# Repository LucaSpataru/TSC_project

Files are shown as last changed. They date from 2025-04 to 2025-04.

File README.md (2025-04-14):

# TSC_project
Pentru acest proiect am avut de implementat PCBul unui ebook reader si asamblarea acestuia in carcasa alaturi de o baterie si display.
Primul pas al proiectului a fost creearea schemei electrice ce consta in plasarea si conectarea componentelor.
Componenta principala este microcontrollerul ESP32-C6 care gestioneaza și coordoneaza functionarea celorlalte componente.
# Pini folositi
| Componentă | Pini ESP C6 | Funcție |
|---|---|---|
| SAMACSYS_PARTS_USB4110-GF-AUSB4 | 13 (USB_D-), 14 (USB_D+) | Încărcare baterie via USB |
| QWIIC_RIGHT_ANGLE + BME680 | 19 (SDA), 20 (SCL) | Măsurare temperatură, calitate aer, umiditate (energy mgmt)  |
| 112A-TAAR-R03_ATTEND (SD card port)  | 4 (SS_SD), 6 (SCK), 7 (MOSI), 27 (MISO) | Transfer de date (card SD) |
| FH34SRJ-24S-0.5SH_99_ (Display header)| 7 (MOSI), 6 (SCK), 11 (EPD_CS), 5 (EPD_DC), 21 (EPD_RST), 26 (EPD_BUSY) | Conectare display |
| W25Q512JVEIQ (64MB Flash extern) | 6 (SCK), 7 (MOSI), 27 (MISO), 12 (FLASH_CS) | Stocare de date |
| Butoane (CHANGE, RESET, BOOT) | 23 (IO/CHANGE), 3 (RESET), 15 (IO/BOOT) | Interfață utilizator (comenzi) |
| DS3231SN# (RTC module) | 8 (INT_RTC), 19 (SDA), 20 (SCL), 9 (32KHZ), 16 (RTC_RST) | Ceas în timp real |

De asemenea sunt implementate test paduri, un regulator de tensiune si linii de protectie pentru a putea asigura functionarea corecta a dispozitivului.

Urmatoarul pas a constat in aranjarea componentelor pe placa, decuparea acesteia pentru a se potrivi in carcasa si pentru a nu incurca alte componente precum microcontrollerul si butoanele,
rutarea semnalelor si desenarea planului de masa pe fata si pe spate.
Am intampinat unele probleme precum marimea padurilor pentru componenta MAX17048G+T10 care nu se potriveau cu regulile de rutare, si marimea padurilor bobinei care erau prea mici - am modificat footprintul componentelor.
Am dat approve la 2 erori comune de tip Board Outline Clearance pentru mufa USB4.
Am plasat componentele cat mai eficient, si de asemenea am aranjat ca numele componentelor sa fie vizibile pe silkscreen.

Mai departe am cautat pentru fiecare componenta folosita modele 3D unde am comparat footprinturile pieselor gasite pentru a alege modelul corespunzator.

Ultimul pas a constat in partea 3D unde am plasat placa in carcasa, aici am facut o modificare ce se poate observa in imaginile buttons_mod, deoarece felul in care am pus butoanele se intersectau cu o bucata de plastic
care am micsorat-o. Butoanele ar trebuii sa functioneze fara probleme acum.
Dupa ce m-am asigurat ca mufele sunt aliniate cu componentele ce ies de pe placa, am creeat un model de baterie si unul de display si le-am aranjat si pe acestea in interiorul dispozitivului.

In cele din urma am generat fisierele BOM, PNP si gerbers care se afla in fisierul Manufacturing.
De asemenea am realizat o animatie cu exploded view, dar si un fisier .step cum este specificat in cerinta.
# BOM
| Componentă | Link de cumpărare |
|---|---|
| ADAFRUIT_LEDCHIP-LED0603 | [Mouser](https://ro.mouser.com/ProductDetail/ams-OSRAM/KW-EELP41.RU-S1U1-3K6L-3X4X-5-R18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) |
| SJ | [Mouser](https://ro.mouser.com/ProductDetail/Chip-Quik/WWSWLT.040-200g?qs=i8QVZAFTkqRTFq30mTreAQ%3D%3D) |
| CPH3225A (Supercapacitor)  | [Mouser](https://ro.mouser.com/ProductDetail/Seiko-Semiconductors/CPH3225A?qs=3etwrb1wR%252BhUOph6lAO7eg%3D%3D) |
| DS3231SN# (RTC) | [SnapEDA](https://www.snapeda.com/parts/DS3231SN%23/Analog+Devices/view-part/?ref=eda) |
| ESP32-C6-WROOM-1-N8 | [SnapEDA](https://www.snapeda.com/parts/ESP32-C6-WROOM-1-N8/Espressif+Systems/view-part/?ref=eda) |
| FH34SRJ-24S-0.5SH_99_ | [Mouser](https://www.mouser.co.uk/ProductDetail/Hirose-Connector/FH34SRJ-24S-0.5SH99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) |
| MAX17048G+T10 (Fuel Gauge)| [SnapEDA](https://www.snapeda.com/parts/MAX17048G+T10/Analog+Devices/view-part/?ref=eda) |
| MBR0530 (Schottky Diode)  | [SnapEDA](https://www.snapeda.com/parts/MBR0530/Onsemi/view-part/?ref=eda) |
| PGB1010603MR (TVS Diode)  | [SnapEDA](https://www.snapeda.com/parts/PGB1010603MR/Littelfuse/view-part/?ref=eda) |
| SI1308EDL-T1-GE3 (MOSFET) | [SnapEDA](https://www.snapeda.com/parts/SI1308EDL-T1-GE3/Vishay+Siliconix/view-part/?ref=eda) |
| USBLC6-2SC6Y (ESD Protection)| [SnapEDA](https://www.snapeda.com/parts/USBLC6-2SC6Y/STMicroelectronics/view-part/?ref=eda) |
| W25Q512JVEIQ (Flash Memory)| [SnapEDA](https://www.snapeda.com/parts/W25Q512JVEIQ/Winbond+Electronics/view-part/?ref=eda) |
| XC6220A331MR-G (LDO Regulator)| [Mouser](https://www.mouser.co.uk/ProductDetail/Torex-Semiconductor/XC6220A331MR-G?qs=AsjdqWjXhJ8ZSWznL1J0gg%3D%3D) |
| BD5229G-TR (Voltage Detector)| [Mouser](https://www.mouser.co.uk/ProductDetail/ROHM-Semiconductor/BD5229G-TR?qs=4kLU8WoGk0vvnhrrYwdszw%3D%3D) |
| BME680 (Environmental Sensor)| [Mouser](https://ro.mouser.com/ProductDetail/Bosch-Sensortec/BME680?qs=v271MhAjFHjo0yA%2FC4OnDQ%3D%3D) |
| 112A-TAAR-R03_ATTEND (SD Card Socket)| [DigiKey](https://www.digikey.ro/en/products/detail/attend-technology/112A-TAAR-R03/17633923) |

# Diagrama
OpenBookDiagram

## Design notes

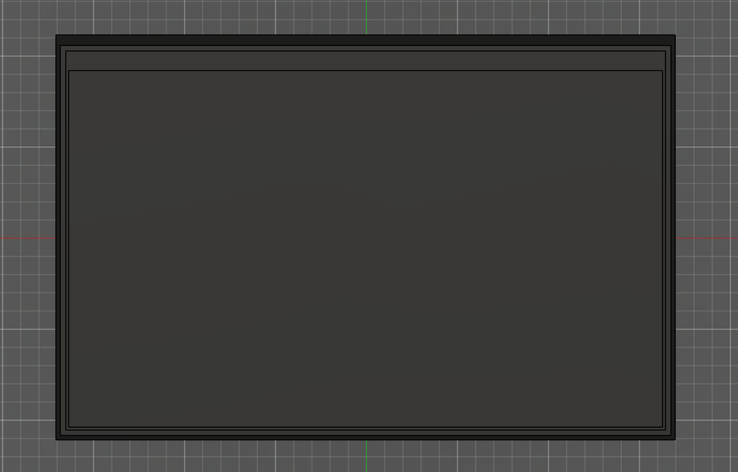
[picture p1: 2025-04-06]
Images/Display_back.png

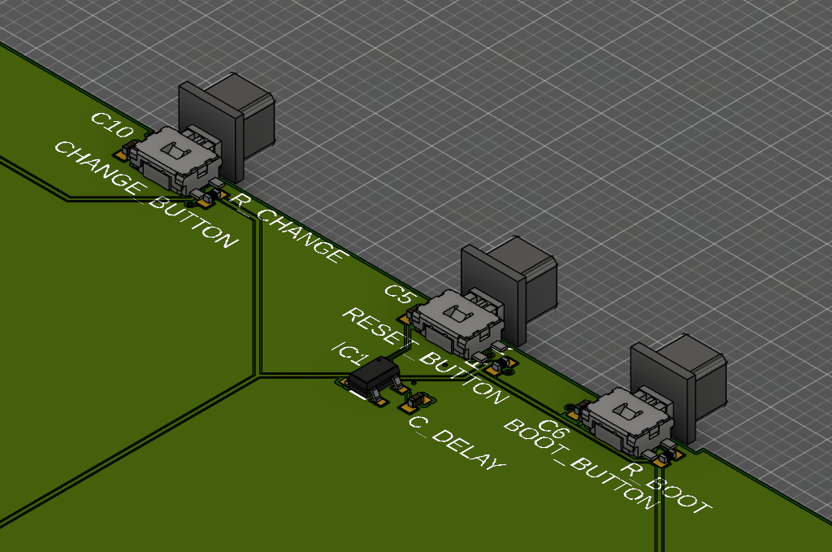
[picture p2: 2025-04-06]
Images/buttons_mod2.png

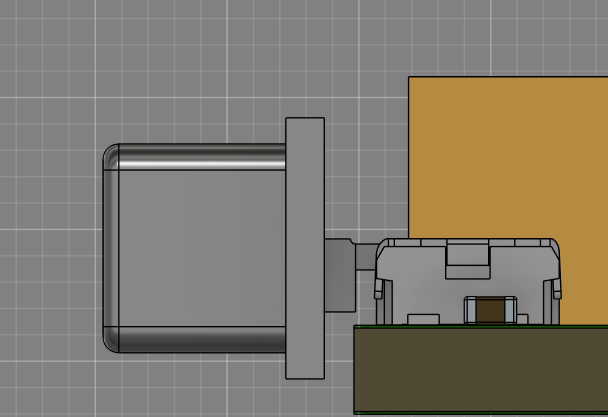
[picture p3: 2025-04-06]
Images/buttons_mod3.png

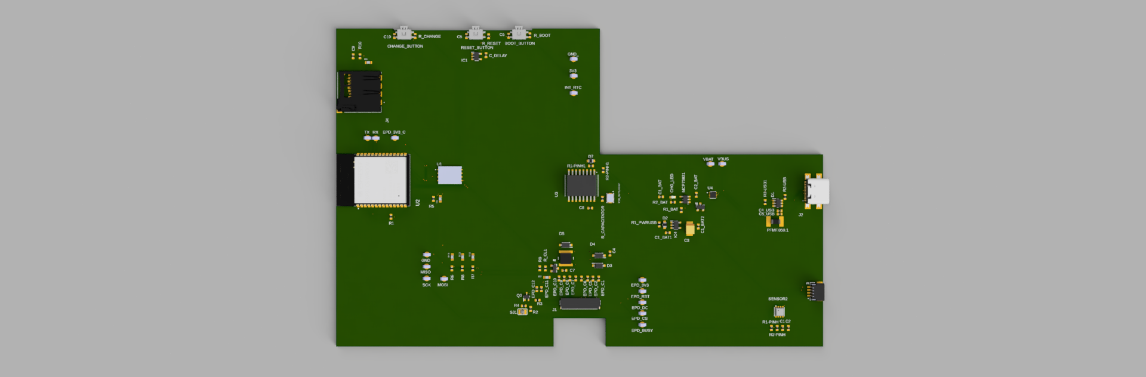
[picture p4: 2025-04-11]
Images/PCB2.png

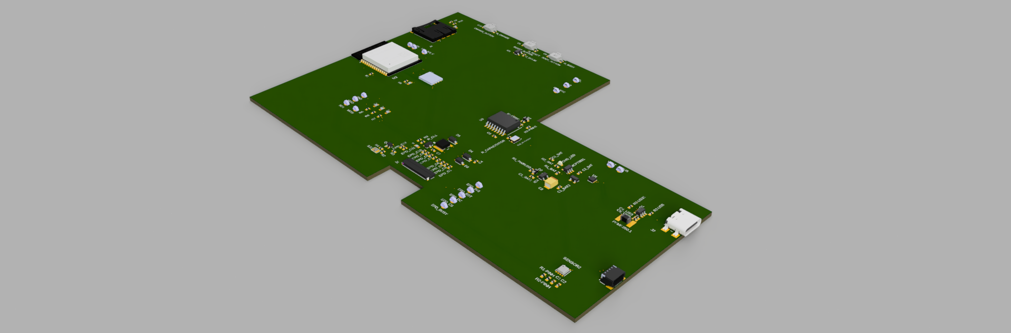
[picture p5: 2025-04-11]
Images/PCB1.png

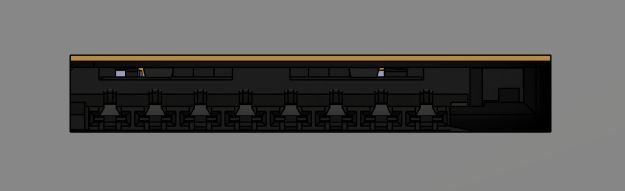
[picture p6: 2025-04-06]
Images/Alignment_2.png

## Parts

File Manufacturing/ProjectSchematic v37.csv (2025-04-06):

Qty | Value | Device | Package | Parts | Description | ARROW_PART_NUMBER | ARROW_PRICE-STOCK | AVAILABILITY | CENTROID_NOT_SPECIFIED | CHECK_PRICES | COPYRIGHT | DATASHEET | DESCRIPTION | DIGIKEY_DESCRIPTION | DIGIKEY_PART_NUMBER | HEIGHT | LEAD_FREE | MANUFACTURER_NAME | MANUFACTURER_PART_NUMBER | MF | MFR_NAME | MOUSER_PART_NUMBER | MOUSER_PRICE-STOCK | MOUSER_TESTING_PART_NUMBER | MOUSER_TESTING_PRICE-STOCK | MP | MPN | PACKAGE | POPULARITY | PREFIX | PRICE | PROD_ID | PURCHASE-URL | ROHS | SNAPEDA_LINK | SPICEMODEL | SPICEPREFIX | TEMPERATURE_RANGE_HIGH | TEMPERATURE_RANGE_LOW | TP_SIGNAL_NAME | VALUE
1 |  | ADAFRUIT_LEDCHIP-LED0603 | ADAFRUIT_CHIP-LED0603 | CHG_LED | LED
1 |  | SJ | SJ | SJ1 | SMD solder JUMPER |  |  |  |  |  |  |  |  |  |  |  |  |  |  |  |  |  |  |  |  |  |  |  | 3
1 | 0.1uF/50V | ESP32_WROVER_EAGLE-LTSPICE_CC0402 | ESP32_WROVER_EAGLE-LTSPICE_C0402 | EPD_C5 | CAPACITOR, European symbol |  |  |  |  |  |  |  |  |  |  |  |  |  |  |  |  |  |  |  |  |  |  |  |  |  |  |  |  |  |  | NONE | C
1 | 0.47 | ESP32_WROVER_EAGLE-LTSPICE_RR0402 | ESP32_WROVER_EAGLE-LTSPICE_R0402 | R3 | RESISTOR, European symbol |  |  |  |  |  |  |  |  |  |  |  |  |  |  |  |  |  |  |  |  |  |  |  |  |  |  |  |  |  |  | NONE | R
1 | 100k | ESP32_WROVER_EAGLE-LTSPICE_RR0402 | ESP32_WROVER_EAGLE-LTSPICE_R0402 | R1_PWRUSB | RESISTOR, European symbol |  |  |  |  |  |  |  |  |  |  |  |  |  |  |  |  |  |  |  |  |  |  |  |  |  |  |  |  |  |  | NONE | R
8 | 100nF | ESP32_WROVER_EAGLE-LTSPICE_CC0402 | ESP32_WROVER_EAGLE-LTSPICE_C0402 | C1, C2, C4_USB, C6, C8, C9, C10, C_DELAY | CAPACITOR, European symbol |  |  |  |  |  |  |  |  |  |  |  |  |  |  |  |  |  |  |  |  |  |  |  |  |  |  |  |  |  |  | NONE | C
1 | 100uF TANT | RCL_CPOL-EUCT3528 | RCL_CT3528 | C3 | POLARIZED CAPACITOR, European symbol |  |  |  |  |  |  |  |  |  |  |  |  |  |  |  |  |  |  |  |  |  |  |  | 0 |  |  |  |  |  |  |  | C
16 | 10k | ESP32_WROVER_EAGLE-LTSPICE_RR0402 | ESP32_WROVER_EAGLE-LTSPICE_R0402 | R1, R1-PINH, R1-PINH1, R2-PINH, R2-PINH1, R4, R5, R6, R7, R8, R9, R10, R_BOOT, R_CHANGE, R_CL1, R_RESET | RESISTOR, European symbol |  |  |  |  |  |  |  |  |  |  |  |  |  |  |  |  |  |  |  |  |  |  |  |  |  |  |  |  |  |  | NONE | R
1 | 10uF | ESP32_WROVER_EAGLE-LTSPICE_CC0402 | ESP32_WROVER_EAGLE-LTSPICE_C0402 | C7 | CAPACITOR, European symbol |  |  |  |  |  |  |  |  |  |  |  |  |  |  |  |  |  |  |  |  |  |  |  |  |  |  |  |  |  |  | NONE | C
1 | 112A-TAAR-R03_ATTEND | 112A-TAAR-R03_ATTEND | 112ATAARR03ATTEND | J4 | Micro SD Card Socket, Push-Push Type, Top Mount, SMT, H=1.83mm, 10u |  |  |  |  |  |  |  | Micro SD Card Socket | Push-Push Type | Top Mount | SMT | H=1.83mm | 10u |  |  | 1.9mm |  | ATTEND | 112A-TAAR-R03 ATTEND
1 | 15 | ESP32_WROVER_EAGLE-LTSPICE_RR0402 | ESP32_WROVER_EAGLE-LTSPICE_R0402 | R_CAPACITATOR | RESISTOR, European symbol |  |  |  |  |  |  |  |  |  |  |  |  |  |  |  |  |  |  |  |  |  |  |  |  |  |  |  |  |  |  | NONE | R
1 | 1uF | ESP32_WROVER_EAGLE-LTSPICE_CC0402 | ESP32_WROVER_EAGLE-LTSPICE_C0402 | C5 | CAPACITOR, European symbol |  |  |  |  |  |  |  |  |  |  |  |  |  |  |  |  |  |  |  |  |  |  |  |  |  |  |  |  |  |  | NONE | C
9 | 1uF/50V | ESP32_WROVER_EAGLE-LTSPICE_CC0402 | ESP32_WROVER_EAGLE-LTSPICE_C0402 | EPD_C1, EPD_C2, EPD_C6, EPD_C7, EPD_C8, EPD_C9, EPD_C10, EPD_C11, EPD_C12 | CAPACITOR, European symbol |  |  |  |  |  |  |  |  |  |  |  |  |  |  |  |  |  |  |  |  |  |  |  |  |  |  |  |  |  |  | NONE | C
1 | 2.2 | ESP32_WROVER_EAGLE-LTSPICE_RR0402 | ESP32_WROVER_EAGLE-LTSPICE_R0402 | R2 | RESISTOR, European symbol |  |  |  |  |  |  |  |  |  |  |  |  |  |  |  |  |  |  |  |  |  |  |  |  |  |  |  |  |  |  | NONE | R
1 | 200 | ESP32_WROVER_EAGLE-LTSPICE_RR0402 | ESP32_WROVER_EAGLE-LTSPICE_R0402 | R1_BAT | RESISTOR, European symbol |  |  |  |  |  |  |  |  |  |  |  |  |  |  |  |  |  |  |  |  |  |  |  |  |  |  |  |  |  |  | NONE | R
2 | 20V/4.2A/52mO/1.4W | ESP32_WROVER_SPARKFUN-DISCRETESEMI_MOSFET_PCH-DMG2305UX-7 | ESP32_WROVER_SPARKFUN-DISCRETESEMI_SOT23-3 | Q1, Q2 | P-channel MOSFETs |  |  |  |  |  |  |  |  |  |  |  |  |  |  |  |  |  |  |  |  |  |  |  |  |  |  | TRAN-14388 |  |  |  |  |  |  |  |  | 20V/4.2A/52mO/1.4W
1 | 2k | ESP32_WROVER_EAGLE-LTSPICE_RR0402 | ESP32_WROVER_EAGLE-LTSPICE_R0402 | R2_BAT | RESISTOR, European symbol |  |  |  |  |  |  |  |  |  |  |  |  |  |  |  |  |  |  |  |  |  |  |  |  |  |  |  |  |  |  | NONE | R
4 | 4.7uF | ESP32_WROVER_EAGLE-LTSPICE_CC0402 | ESP32_WROVER_EAGLE-LTSPICE_C0402 | C1_BAT, C1_BAT1, C2_BAT, C5_USB | CAPACITOR, European symbol |  |  |  |  |  |  |  |  |  |  |  |  |  |  |  |  |  |  |  |  |  |  |  |  |  |  |  |  |  |  | NONE | C
1 | 4.7uF/25V | ESP32_WROVER_EAGLE-LTSPICE_CC0402 | ESP32_WROVER_EAGLE-LTSPICE_C0402 | C4 | CAPACITOR, European symbol |  |  |  |  |  |  |  |  |  |  |  |  |  |  |  |  |  |  |  |  |  |  |  |  |  |  |  |  |  |  | NONE | C
1 | 4.7uF\ | ESP32_WROVER_EAGLE-LTSPICE_CC0402 | ESP32_WROVER_EAGLE-LTSPICE_C0402 | C1_BAT2 | CAPACITOR, European symbol |  |  |  |  |  |  |  |  |  |  |  |  |  |  |  |  |  |  |  |  |  |  |  |  |  |  |  |  |  |  | NONE | C
2 | 5k1 | ESP32_WROVER_EAGLE-LTSPICE_RR0402 | ESP32_WROVER_EAGLE-LTSPICE_R0402 | R2-USB, R2-USB1 | RESISTOR, European symbol |  |  |  |  |  |  |  |  |  |  |  |  |  |  |  |  |  |  |  |  |  |  |  |  |  |  |  |  |  |  | NONE | R
1 | 68uH | 744043680IND_4828-WE-TPC_WRE | IND_4828-WE-TPC_WRE | L1 |  |  |  |  |  |  | Copyright (C) 2024 Ultra Librarian. All rights reserved. |  |  |  |  |  |  |  | 744043680 |  | Wurth Electronics
1 | BD5229G-TR | BD5229G-TR | SOT95P280X125-5N | IC1 | Voltage Detector with Adjustable Delay Time: CMOS processes are utilized to develop high precision, low current consumption CMOS reset ICs that allow arbitrary setting of the delay time. The extensive lineup includes both Nch Open Drain and CMOS output types in a wide range of detection voltages (from 2.3V to 6.0V, in 0.1V steps), enabling selection of the ideal solution based on customer requirements. In addition, the entire series is of course both lead-free and RoHS-compliant. |  |  |  |  |  |  |  | Voltage Detector with Adjustable Delay Time: CMOS processes are utilized to develop high precision | low current consumption CMOS reset ICs that allow arbitrary setting of the delay time. The extensive lineup includes both Nch Open Drain and CMOS output types in a wide range of detection voltages (from 2.3V to 6.0V | in 0.1V steps) | enabling selection of the ideal solution based on customer requirements. In addition | the entire series is of course both lead-free and RoHS-compliant. |  |  | 1.25mm |  | ROHM Semiconductor | BD5229G-TR |  |  | 755-BD5229G-TR | https://www.mouser.co.uk/ProductDetail/ROHM-Semiconductor/BD5229G-TR?qs=4kLU8WoGk0vvnhrrYwdszw%3D%3D
1 | BME680 | ESP32_WROVER_BME680_BME680 | ESP32_WROVER_BME680_PSON80P300X300X100-8N | SENSOR2 | Integrated Environmental Unit |  |  | Unavailable |  |  |  |  | Integrated Environmental Unit |  |  |  |  |  |  | Bosch Sensortec |  |  |  |  |  | BME680 |  | LGA-8 Bosch Tools |  |  | None
3 | BUTTON_CUSYOMV1 | BUTTON_CUSYOMV1 | MYBUTTON | BOOT_BUTTON, CHANGE_BUTTON, RESET_BUTTON
1 | CPH3225A | CPH3225A | CAPCP3225X100N | C10_SUPERCAP | Cap 0.011F 3.3V 1210 Flat Check availability |  |  | Not in stock |  | https://www.snapeda.com/parts/CPH3225A/Seiko+Instruments/view-part/?ref=eda |  |  | 11 mF (EDLC) Supercapacitor 3.3 V 1210 (3225 Metric) - - |  |  |  |  |  |  | Seiko Instruments |  |  |  |  |  | CPH3225A |  | 1210 Seiko |  |  | None |  | https://www.snapeda.com/api/url_track_click_mouser/?unipart_id=562593&manufacturer=Seiko Instruments&part_name=CPH3225A&search_term=None |  | https://www.snapeda.com/parts/CPH3225A/Seiko+Instruments/view-part/?ref=snap
1 | DS3231SN# | DS3231SN# | SOIC127P1032X265-16N | U3 | Real Time Clock Serial 16-Pin SOIC W T/R Check availability |  |  | In Stock |  | https://www.snapeda.com/parts/DS3231SN%23/Analog+Devices/view-part/?ref=eda |  |  | Extremely Accurate I²C-Integrated RTC/TCXO/Crystal |  |  |  |  |  |  | Analog Devices |  |  |  |  |  | DS3231SN# |  | SOIC-16 Maxim |  |  | None |  | https://www.snapeda.com/api/url_track_click_mouser/?unipart_id=99048&manufacturer=Analog Devices&part_name=DS3231SN#&search_term=None |  | https://www.snapeda.com/parts/DS3231SN%23/Analog+Devices/view-part/?ref=snap
1 | ESP32-C6-WROOM-1-N8 | ESP32-C6-WROOM-1-N8 | XCVR_ESP32-C6-WROOM-1-N8 | U2 | Check availability |  |  | In Stock |  | https://www.snapeda.com/parts/ESP32-C6-WROOM-1-N8/Espressif+Systems/view-part/?ref=eda |  |  | Multiprotocol Modules ESP32-C6 module | Wi-Fi 6 in 2.4 GHz band | Bluetooth 5 | Zigbee 3.0 and Thread. ESP34-WROOM Compatible - ENGINEERING SAMPLE |  |  |  |  |  |  | Espressif Systems |  |  |  |  |  | ESP32-C6-WROOM-1-N8 |  | None |  |  | None |  |  |  | https://www.snapeda.com/parts/ESP32-C6-WROOM-1-N8/Espressif+Systems/view-part/?ref=snap
1 | ESP32C6_VARISTORCN1812 | ESP32C6_VARISTORCN1812 | ESP32C6_VARISTOR_CT/CN1812 | PFMF.050.1 | VARISTOR |  |  |  |  |  |  |  |  |  |  |  |  |  |  |  |  |  |  |  |  |  |  |  | 0
2 | ESP32_WROVER_AVX---SD0805S020S1R0_AVX_SD0805S020S1R0_0_0AVX_SD0805S020S1R0_0_0 | ESP32_WROVER_AVX---SD0805S020S1R0_AVX_SD0805S020S1R0_0_0AVX_SD0805S020S1R0_0_0 | ESP32_WROVER_AVX---SD0805S020S1R0_AVX_SD0805S020S1R0_0 | D2, D7 | Schottky Barrier Rectifier Diode |  |  |  | No |  |  | http://datasheets.avx.com/schottky.pdf |  | DIODE SCHOTTKY 20V 1A 0805 | 478-7800-1-ND |  | yes |  |  | AVX |  | 581-SD0805S020S1R0 |  |  |  |  |  | 0805 (2012 metric) |  | D |  |  |  | yes |  |  |  | +125°C | -55°C
1 | ESP32_WROVER_SPARKFUN-IC-POWER_MCP73831 | ESP32_WROVER_SPARKFUN-IC-POWER_MCP73831 | ESP32_WROVER_SPARKFUN-IC-POWER_SOT23-5 | MCP73831 | MCP73831T Li-Ion, Li-Pol Controller |  |  |  |  |  |  |  |  |  |  |  |  |  |  |  |  |  |  |  |  |  |  |  |  |  |  | IC-09995
1 | FH34SRJ-24S-0.5SH_99_ | FH34SRJ-24S-0.5SH_99_ | FH34SRJ24S05SH99 | J1 | (0.50mm) Surface Mount, Right Angle |  |  |  |  |  |  |  | 24 Position FFC | FPC Connector Contacts | (0.50mm) Surface Mount | Right Angle |  |  | 1.1mm |  | Hirose | FH34SRJ-24S-0.5SH(99) |  |  | 798-FH34SRJ24S05SH99 | https://www.mouser.co.uk/ProductDetail/Hirose-Connector/FH34SRJ-24S-0.5SH99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
1 | MAX17048G+T10 | MAX17048G+T10 | SON50P200X200X80-9N | U4 | Check availability |  |  | In Stock |  | https://www.snapeda.com/parts/MAX17048G+T10/Analog+Devices/view-part/?ref=eda |  |  | 3µA 1-Cell/2-Cell Fuel Gauge with ModelGauge |  |  |  |  |  |  | Analog Devices |  |  |  |  |  | MAX17048G+T10 |  | TDFN-8 Maxim |  |  | None |  | https://www.snapeda.com/api/url_track_click_mouser/?unipart_id=329239&manufacturer=Analog Devices&part_name=MAX17048G+T10&search_term=None |  | https://www.snapeda.com/parts/MAX17048G+T10/Analog+Devices/view-part/?ref=snap
3 | MBR0530 | MBR0530 | SOD3716X135N | D3, D4, D5 | ON SEMICONDUCTOR - MBR0530 - DIODE, SCHOTTKY, 0.5A, 30V, SOD-123 |  |  | In Stock |  | https://www.snapeda.com/parts/MBR0530/Onsemi/view-part/?ref=eda |  |  | Diode Schottky 30 V 500mA Surface Mount SOD-123 |  |  |  |  |  |  | ON Semiconductor |  |  |  |  |  | MBR0530 |  | SOD-123-2 ON Semiconductor |  |  | None |  | https://www.snapeda.com/api/url_track_click_mouser/?unipart_id=179458&manufacturer=ON Semiconductor&part_name=MBR0530&search_term=None |  | https://www.snapeda.com/parts/MBR0530/Onsemi/view-part/?ref=snap
6 | PGB1010603MR | PGB1010603MR | DIOC1608X36N | D6, D8, D9, D10, D11, D12 | Check availability |  |  | In Stock |  | https://www.snapeda.com/parts/PGB1010603MR/Littelfuse/view-part/?ref=eda |  |  | 150V (Typ) Clamp - Ipp Tvs Diode Surface Mount 0603 (1608 Metric) |  |  |  |  |  |  | Littelfuse Inc. |  |  |  |  |  | PGB1010603MR |  | 0603 Littelfuse Inc. |  |  | None |  | https://www.snapeda.com/api/url_track_click_mouser/?unipart_id=5659453&manufacturer=Littelfuse Inc.&part_name=PGB1010603MR&search_term=None |  | https://www.snapeda.com/parts/PGB1010603MR/Littelfuse/view-part/?ref=snap
1 | QWIIC_RIGHT_ANGLE | QWIIC_CONNECTORJS-1MM | JST04_1MM_RA | J3 | SparkFun I2C Standard Qwiic Connector |  |  |  |  |  |  |  |  |  |  |  |  |  |  |  |  |  |  |  |  |  |  |  |  |  |  | CONN-13694 |  |  |  |  |  |  |  |  | QWIIC_RIGHT_ANGLE
1 | SAMACSYS_PARTS_USB4110-GF-AUSB4 | SAMACSYS_PARTS_USB4110-GF-AUSB4 | SAMACSYS_PARTS_USB4110GFA | J2 | CONN USB 2.0 TYPE-C R/A SMT
1 | SI1308EDL-T1-GE3 | SI1308EDL-T1-GE3 | SOT65P210X110-3N | Q3 | MOSFET N-Ch 30V 1.5A TrenchFET SC70 Vishay Si1308EDL-T1-GE3 N-channel MOSFET Transistor, 1.5 A, 30 V, 3-Pin SC-70 |  |  | In Stock |  | https://www.snapeda.com/parts/SI1308EDL-T1-GE3/Vishay+Siliconix/view-part/?ref=eda |  |  | Si1308EDL-T1-GE3 N-channel MOSFET Transistor | 1.5 A | 30 V | 3-Pin SC-70 | Siliconix / Vishay SI1308EDL-T1-GE3 |  |  |  |  |  |  | Vishay Siliconix |  |  |  |  |  | SI1308EDL-T1-GE3 |  | SOT-323 Vishay Semiconductor |  |  | None |  | https://www.snapeda.com/api/url_track_click_mouser/?unipart_id=274603&manufacturer=Vishay Siliconix&part_name=SI1308EDL-T1-GE3&search_term=None |  | https://www.snapeda.com/parts/SI1308EDL-T1-GE3/Vishay+Siliconix/view-part/?ref=snap
17 | TPTP20R | TPTP20R | TP20R | 3V3, EPD_3V3, EPD_3V3_C, EPD_BUSY, EPD_CS, EPD_DC, EPD_RST, GND, GND_, INT_RTC, MISO, MOSI, RX, SCK, TX, VBAT, VBUS | Test pad |  |  |  |  |  |  |  |  |  |  |  |  |  |  |  |  |  |  |  |  |  |  |  | 2
1 | USBLC6-2SC6Y | USBLC6-2SC6Y | SOT95P280X145-6N | D1 | Low Cap. ESD Protection Auto SOT-23-6 STMicroelectronics USBLC6-2SC6Y, Dual Uni-Directional TVS Diode Array, 6-Pin SOT-23 |  |  | In Stock |  | https://www.snapeda.com/parts/USBLC6-2SC6Y/STMicroelectronics/view-part/?ref=eda |  |  | 17V Clamp 5A (8/20µs) Ipp Tvs Diode Surface Mount SOT-23-6 |  |  |  |  |  |  | STMicroelectronics |  |  |  |  |  | USBLC6-2SC6Y |  | SOT-23-6 STMicroelectronics |  |  | None |  |  |  | https://www.snapeda.com/parts/USBLC6-2SC6Y/STMicroelectronics/view-part/?ref=snap
1 | W25Q512JVEIQ | W25Q512JVEIQ | SON127P600X800X80-9N | U1 | Check availability |  |  | In Stock |  | https://www.snapeda.com/parts/W25Q512JVEIQ/Winbond+Electronics/view-part/?ref=eda |  |  | FLASH - NOR Memory IC 512Mb (64M x 8) SPI - Quad I/O 133 MHz 8-WSON (8x6) |  |  |  |  |  |  | Winbond Electronics |  |  |  |  |  | W25Q512JVEIQ |  | Package |  |  | None |  |  |  | https://www.snapeda.com/parts/W25Q512JVEIQ/Winbond+Electronics/view-part/?ref=snap
1 | XC6220A331MR-G | XC6220A331MR-G | SOT95P280X120-5N | IC4 | LDO Voltage Regulators |  |  |  |  |  |  |  | LDO Voltage Regulators |  |  | 1.2mm |  | Torex | XC6220A331MR-G |  |  | 865-XC6220A331MR-G | https://www.mouser.co.uk/ProductDetail/Torex-Semiconductor/XC6220A331MR-G?qs=AsjdqWjXhJ8ZSWznL1J0gg%3D%3D

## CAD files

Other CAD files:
Mechanical/ProjectDesign.f3z

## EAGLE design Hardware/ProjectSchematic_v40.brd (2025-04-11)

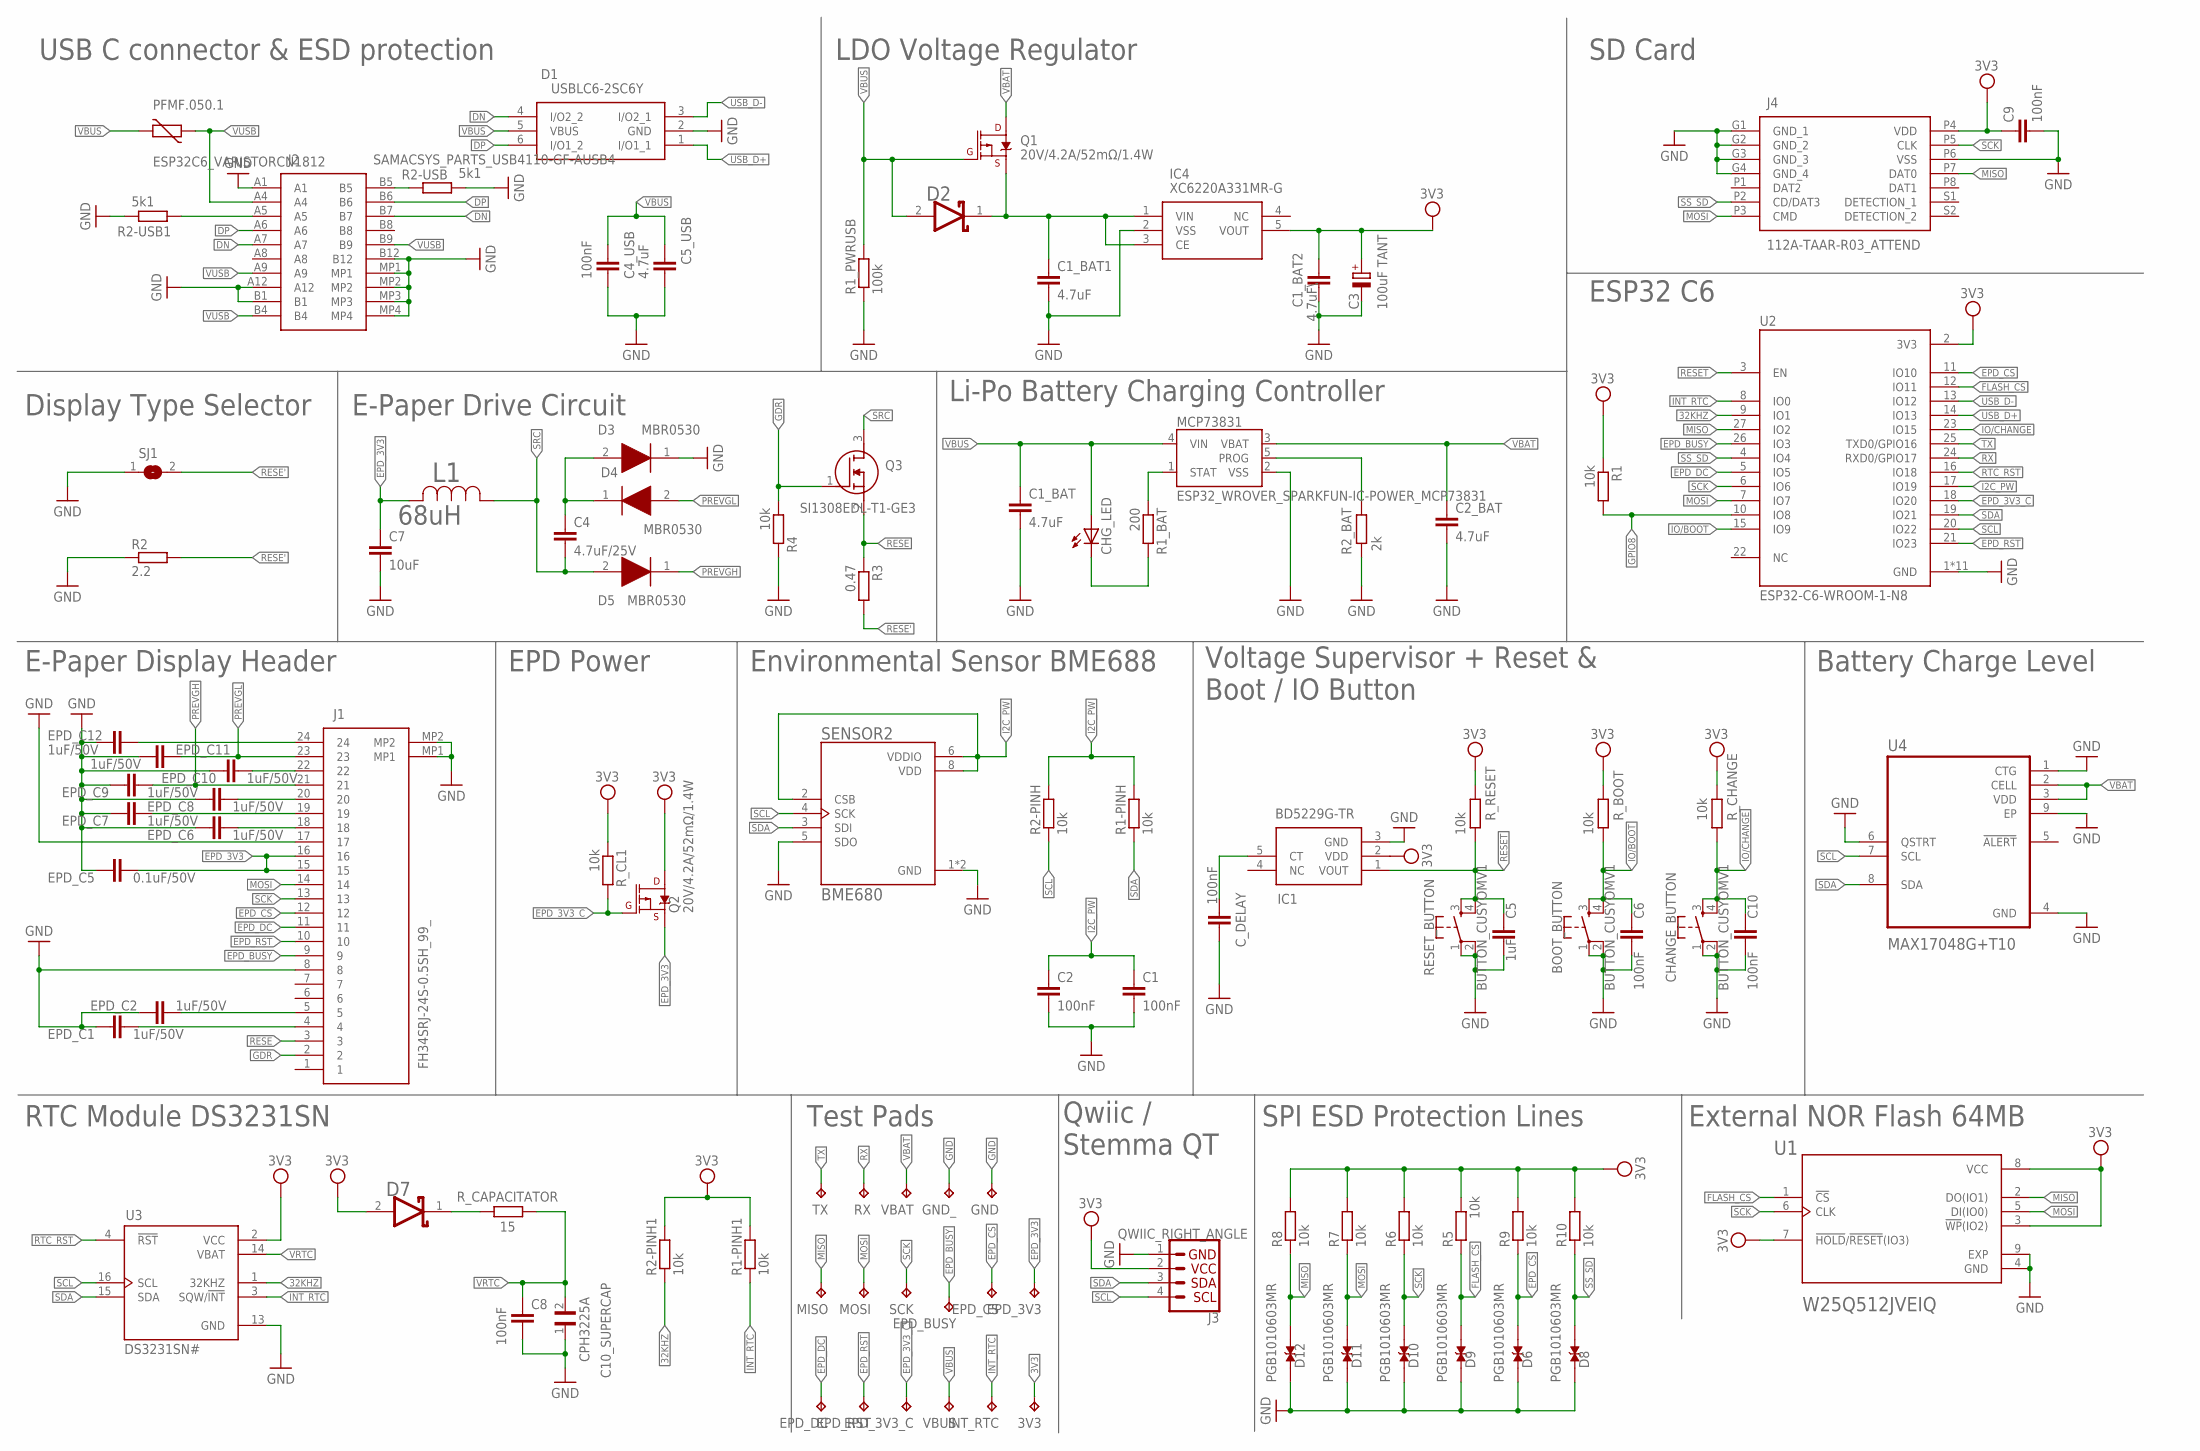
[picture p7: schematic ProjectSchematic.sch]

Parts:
3V3: TPTP20R; TP20R
BOOT_BUTTON: BUTTON_CUSYOMV1; MYBUTTON
C1, C2, C4_USB, C6, C8, C9, C10: 100nF; ESP32_WROVER_EAGLE-LTSPICE_C0402
C1_BAT, C1_BAT1, C2_BAT, C5_USB: 4.7uF; ESP32_WROVER_EAGLE-LTSPICE_C0402
C1_BAT2: 4.7uF\; ESP32_WROVER_EAGLE-LTSPICE_C0402
C3: 100uF TANT; RCL_CT3528
C4: 4.7uF/25V; ESP32_WROVER_EAGLE-LTSPICE_C0402
C5: 1uF; ESP32_WROVER_EAGLE-LTSPICE_C0402
C7: 10uF; ESP32_WROVER_EAGLE-LTSPICE_C0402
C10_SUPERCAP: CPH3225A; CAPCP3225X100N
CHANGE_BUTTON: BUTTON_CUSYOMV1; MYBUTTON
CHG_LED: ADAFRUIT_LEDCHIP-LED0603; ADAFRUIT_CHIP-LED0603
C_DELAY: 100nF; ESP32_WROVER_EAGLE-LTSPICE_C0402
D1: USBLC6-2SC6Y; SOT95P280X145-6N
D2, D7: ESP32_WROVER_AVX---SD0805S020S1R0_AVX_SD0805S020S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; ESP32_WROVER_AVX---SD0805S020S1R0_AVX_SD0805S020S1R0_0
D3, D4, D5: MBR0530; SOD3716X135N
D6, D8, D9, D10, D11, D12: PGB1010603MR; DIOC1608X36N
EPD_3V3, EPD_3V3_C: TPTP20R; TP20R
EPD_BUSY: TPTP20R; TP20R
EPD_C1, EPD_C2, EPD_C6, EPD_C7, EPD_C8, EPD_C9, EPD_C10, EPD_C11, EPD_C12: 1uF/50V; ESP32_WROVER_EAGLE-LTSPICE_C0402
EPD_C5: 0.1uF/50V; ESP32_WROVER_EAGLE-LTSPICE_C0402
EPD_CS: TPTP20R; TP20R
EPD_DC: TPTP20R; TP20R
EPD_RST: TPTP20R; TP20R
GND: TPTP20R; TP20R
GND_: TPTP20R; TP20R
IC1: BD5229G-TR; SOT95P280X125-5N
IC4: XC6220A331MR-G; SOT95P280X120-5N
INT_RTC: TPTP20R; TP20R
J1: FH34SRJ-24S-0.5SH_99_; FH34SRJ24S05SH99
J2: SAMACSYS_PARTS_USB4110-GF-AUSB4; SAMACSYS_PARTS_USB4110GFA
J3: QWIIC_RIGHT_ANGLE; JST04_1MM_RA
J4: 112A-TAAR-R03_ATTEND; 112ATAARR03ATTEND
L1: 68uH; IND_4828-WE-TPC_WRE
MCP73831: ESP32_WROVER_SPARKFUN-IC-POWER_MCP73831; ESP32_WROVER_SPARKFUN-IC-POWER_SOT23-5
MISO: TPTP20R; TP20R
MOSI: TPTP20R; TP20R
PFMF.050.1: ESP32C6_VARISTORCN1812; ESP32C6_VARISTOR_CT/CN1812
Q1, Q2: 20V/4.2A/52mΩ/1.4W; ESP32_WROVER_SPARKFUN-DISCRETESEMI_SOT23-3
Q3: SI1308EDL-T1-GE3; SOT65P210X110-3N
R1, R1-PINH, R1-PINH1, R2-PINH, R2-PINH1, R4, R5, R6, R7, R8, R9, R10: 10k; ESP32_WROVER_EAGLE-LTSPICE_R0402
R1_BAT: 200; ESP32_WROVER_EAGLE-LTSPICE_R0402
R1_PWRUSB: 100k; ESP32_WROVER_EAGLE-LTSPICE_R0402
R2: 2.2; ESP32_WROVER_EAGLE-LTSPICE_R0402
R2-USB, R2-USB1: 5k1; ESP32_WROVER_EAGLE-LTSPICE_R0402
R2_BAT: 2k; ESP32_WROVER_EAGLE-LTSPICE_R0402
R3: 0.47; ESP32_WROVER_EAGLE-LTSPICE_R0402
RESET_BUTTON: BUTTON_CUSYOMV1; MYBUTTON
RX: TPTP20R; TP20R
R_BOOT: 10k; ESP32_WROVER_EAGLE-LTSPICE_R0402
R_CAPACITATOR: 15; ESP32_WROVER_EAGLE-LTSPICE_R0402
R_CHANGE: 10k; ESP32_WROVER_EAGLE-LTSPICE_R0402
R_CL1: 10k; ESP32_WROVER_EAGLE-LTSPICE_R0402
R_RESET: 10k; ESP32_WROVER_EAGLE-LTSPICE_R0402
SCK: TPTP20R; TP20R
SENSOR2: BME680; ESP32_WROVER_BME680_PSON80P300X300X100-8N
SJ1: SJ
TX: TPTP20R; TP20R
U1: W25Q512JVEIQ; SON127P600X800X80-9N
U2: ESP32-C6-WROOM-1-N8; XCVR_ESP32-C6-WROOM-1-N8
U3: DS3231SN#; SOIC127P1032X265-16N
U4: MAX17048G+T10; SON50P200X200X80-9N
VBAT: TPTP20R; TP20R
VBUS: TPTP20R; TP20R

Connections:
3V3: 3V3.TP, C1_BAT2.1, C3.+, C9.1, D7.2 (ANODE), IC1.2 (VDD), IC4.5 (VOUT), J3.2, J4.P4 (VDD), Q2.3 (D), R1.1, R1-PINH1.2, R2-PINH1.2, R5.2, R6.2, R7.2, R8.2, R9.2, R10.2, R_BOOT.2, R_CHANGE.2, R_CL1.1, R_RESET.2, U1.3 (!WP!(IO2)), U1.7 (!HOLD!/!RESET!(IO3)), U1.8 (VCC), U2.2 (3V3), U3.2 (VCC)
32KHZ: R2-PINH1.1, U2.9 (IO1), U3.1 (32KHZ)
DN: D1.4 (I/O2_2), J2.A7, J2.B7
DP: D1.6 (I/O1_2), J2.A6, J2.B6
EPD_3V3: C7.1, EPD_3V3.TP, EPD_C5.1, J1.15, J1.16, L1.2, Q2.2 (S)
EPD_3V3_C: EPD_3V3_C.TP, Q2.1 (G), R_CL1.2, U2.18 (IO20)
EPD_BUSY: EPD_BUSY.TP, J1.9, U2.26 (IO3)
EPD_CS: D6.2, EPD_CS.TP, J1.12, R9.1, U2.11 (IO10)
EPD_DC: EPD_DC.TP, J1.11, U2.5 (IO5)
EPD_RST: EPD_RST.TP, J1.10, U2.21 (IO23)
FLASH_CS: D9.2, R5.1, U1.1 (!CS), U2.12 (IO11)
GDR: J1.2, Q3.1 (G), R4.1
GND: BOOT_BUTTON.1, BOOT_BUTTON.2, C1.2, C1_BAT.2, C1_BAT1.2, C1_BAT2.2, C2.2, C2_BAT.2, C3.-, C4_USB.2, C5.2, C5_USB.2, C6.2, C7.2, C8.2, C9.2, C10.2, C10_SUPERCAP.1, CHANGE_BUTTON.1, CHANGE_BUTTON.2, C_DELAY.2, D1.2 (GND), D3.1 (K), D6.1, D8.1, D9.1, D10.1, D11.1, D12.1, EPD_C1.2, EPD_C2.2, EPD_C5.2, EPD_C6.2, EPD_C7.2, EPD_C8.2, EPD_C9.2, EPD_C10.2, EPD_C11.2, EPD_C12.2, GND.TP, GND_.TP, IC1.3 (GND), IC4.2 (VSS), J1.8, J1.17, J1.MP1, J1.MP2, J2.A1, J2.A12, J2.B1, J2.B12, J2.MP1, J2.MP2, J2.MP3, J2.MP4, J3.1, J4.G1 (GND_1), J4.G2 (GND_2), J4.G3 (GND_3), J4.G4 (GND_4), J4.P6 (VSS), MCP73831.2 (VSS), R1_PWRUSB.1, R2.1, R2-USB.2, R2-USB1.1, R2_BAT.2, R4.2, RESET_BUTTON.1, RESET_BUTTON.2, SENSOR2.1 (GND), SENSOR2.5 (SDO), SENSOR2.7 (GND), SJ1.1, U1.4 (GND), U1.9 (EXP), U2.1 (GND), U2.28 (GND), U2.29_1 (GND), U2.29_2 (GND), U2.29_3 (GND), U2.29_4 (GND), U2.29_5 (GND), U2.29_6 (GND), U2.29_7 (GND), U2.29_8 (GND), U2.29_9 (GND), U3.13 (GND), U4.1 (CTG), U4.4 (GND), U4.6 (QSTRT), U4.9 (EP)
GPIO8: R1.2, U2.10 (IO8)
I2C_PW: C1.1, C2.1, R1-PINH.2, R2-PINH.2, SENSOR2.2 (CSB), SENSOR2.6 (VDDIO), SENSOR2.8 (VDD), U2.17 (IO19)
INT_RTC: INT_RTC.TP, R1-PINH1.1, U2.8 (IO0), U3.3 (SQW/!INT)
IO/BOOT: BOOT_BUTTON.3, BOOT_BUTTON.4, C6.1, R_BOOT.1, U2.15 (IO9)
IO/CHANGE: C10.1, CHANGE_BUTTON.3, CHANGE_BUTTON.4, R_CHANGE.1, U2.23 (IO15)
MISO: D12.2, J4.P7 (DAT0), MISO.TP, R8.1, U1.2 (DO(IO1)), U2.27 (IO2)
MOSI: D11.2, J1.14, J4.P3 (CMD), MOSI.TP, R7.1, U1.5 (DI(IO0)), U2.7 (IO7)
unnamed: J2.B5, R2-USB.1
unnamed: J2.A5, R2-USB1.2
unnamed: C_DELAY.1, IC1.5 (CT)
unnamed: MCP73831.1 (STAT), R1_BAT.1
unnamed: C1_BAT1.1, D2.1 (CATHODE), IC4.1 (VIN), IC4.3 (CE), Q1.2 (S)
unnamed: CHG_LED.C, R1_BAT.2
unnamed: C4.1, D3.2 (A), D4.1 (K)
unnamed: MCP73831.5 (PROG), R2_BAT.1
unnamed: EPD_C2.1, J1.5
unnamed: EPD_C1.1, J1.4
unnamed: D7.1 (CATHODE), R_CAPACITATOR.2
unnamed: EPD_C12.1, J1.24
unnamed: EPD_C10.1, J1.22
unnamed: EPD_C7.1, J1.19
unnamed: EPD_C8.1, J1.20
unnamed: EPD_C6.1, J1.18
PREVGH: D5.1 (K), EPD_C9.1, J1.21
PREVGL: D4.2 (A), EPD_C11.1, J1.23
RESE: J1.3, Q3.2 (S), R3.1
RESE': R2.2, R3.2, SJ1.2
RESET: C5.1, IC1.1 (VOUT), RESET_BUTTON.3, RESET_BUTTON.4, R_RESET.1, U2.3 (EN)
RTC_RST: U2.16 (IO18), U3.4 (!RST)
RX: RX.TP, U2.24 (RXD0/GPIO17)
SCK: D10.2, J1.13, J4.P5 (CLK), R6.1, SCK.TP, U1.6 (CLK), U2.6 (IO6)
SCL: J3.4, R2-PINH.1, SENSOR2.4 (SCK), U2.20 (IO22), U3.16 (SCL), U4.7 (SCL)
SDA: J3.3, R1-PINH.1, SENSOR2.3 (SDI), U2.19 (IO21), U3.15 (SDA), U4.8 (SDA)
SRC: C4.2, D5.2 (A), L1.1, Q3.3 (D)
SS_SD: D8.2, J4.P2 (CD/DAT3), R10.1, U2.4 (IO4)
TX: TX.TP, U2.25 (TXD0/GPIO16)
USB_D+: D1.1 (I/O1_1), U2.14 (IO13)
USB_D-: D1.3 (I/O2_1), U2.13 (IO12)
VBAT: C2_BAT.1, MCP73831.3 (VBAT), Q1.3 (D), U4.2 (CELL), U4.3 (VDD), VBAT.TP
VBUS: C1_BAT.1, C4_USB.1, C5_USB.1, CHG_LED.A, D1.5 (VBUS), D2.2 (ANODE), MCP73831.4 (VIN), PFMF.050.1.2, Q1.1 (G), R1_PWRUSB.2, VBUS.TP
VRTC: C8.1, C10_SUPERCAP.2, R_CAPACITATOR.1, U3.14 (VBAT)
VUSB: J2.A4, J2.A9, J2.B4, J2.B9, PFMF.050.1.1

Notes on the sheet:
USB C connector & ESD protection
LDO Voltage Regulator
SD Card
Display Type Selector
E-Paper Drive Circuit
Li-Po Battery Charging Controller
ESP32 C6
E-Paper Display Header
EPD Power
Environmental Sensor BME688
Voltage Supervisor + Reset & Boot / IO Button
Battery Charge Level
RTC Module DS3231SN
Test Pads
Qwiic / Stemma QT
SPI ESD Protection Lines
External NOR Flash 64MB

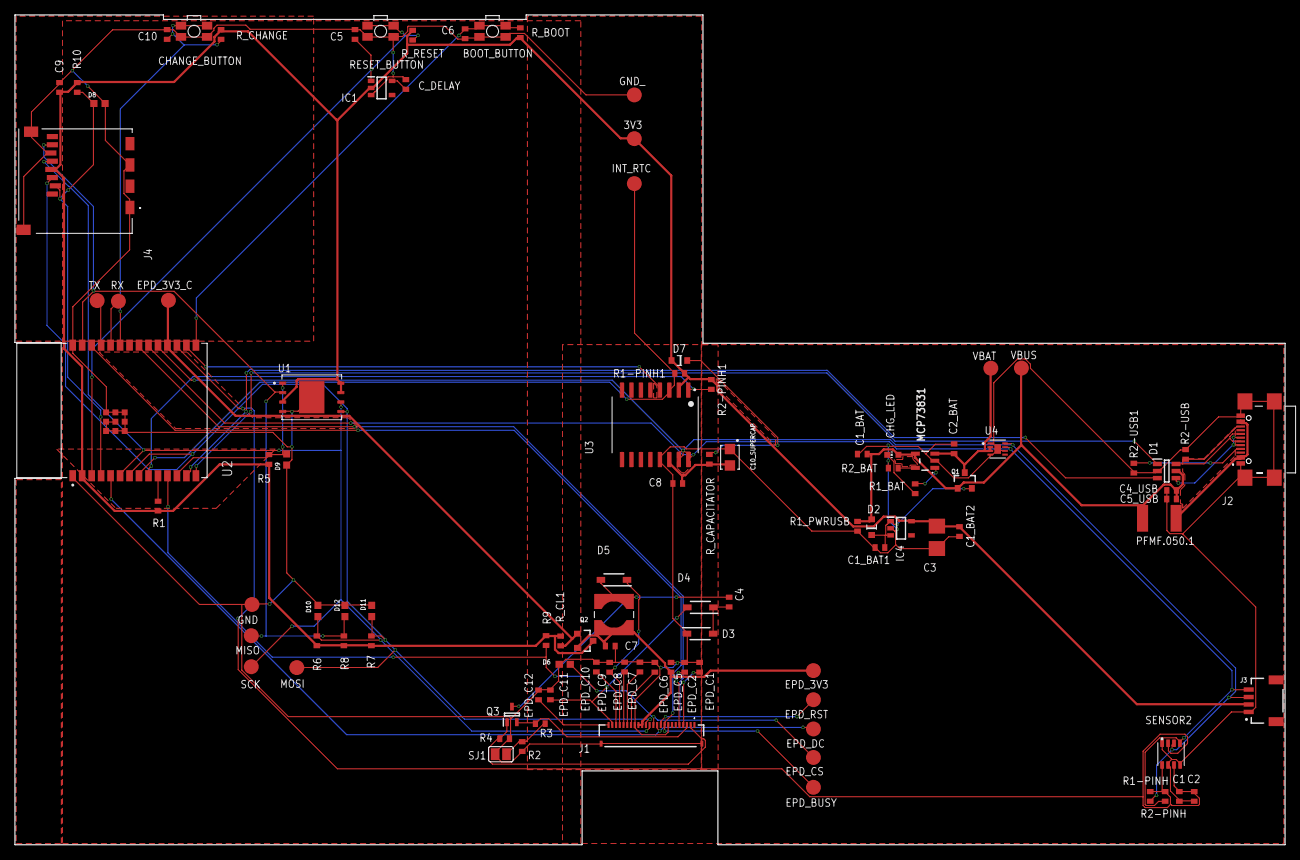
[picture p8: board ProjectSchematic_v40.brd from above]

Board: 2 copper layers, 170.2 x 111.2 mm, 103 parts (0 on the bottom side), 55 nets.

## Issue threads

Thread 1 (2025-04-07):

Silkscreen-ul contine valori

BogdanValentin, 2025-04-07:
Conform regulei 12: Layer-ul de silkscreen trebuie să fie citeț și să conțină doar numele componentelor, nu și valorile acestora.

LucaSpataru, 2025-04-14:
Am rezolvat problema si am modificat fisierele corespunzatoare.

Closed 2025-04-14.

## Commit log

2025-04-11 Am modificat valorile de pe silk screen
2025-04-11 Am sters fisiere adaugate din greseala
    [ProjectBoard.brd]
2025-04-11 Create ProjectSchematic_v40.brd
    Am rearanjat numele pe silk screen si am sters valorile
    [ProjectSchematic_v40.brd]
2025-04-14 Am sters designul vechi
    [ProjectDesignV1.f3z]
2025-04-14 Am adaugat designul modificat
    [ProjectDesign.f3z]
2025-04-14 Update README.md
    Am adaugat tabel BOM si am realizat modificari estetice

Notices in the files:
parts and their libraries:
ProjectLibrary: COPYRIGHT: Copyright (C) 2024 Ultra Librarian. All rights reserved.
